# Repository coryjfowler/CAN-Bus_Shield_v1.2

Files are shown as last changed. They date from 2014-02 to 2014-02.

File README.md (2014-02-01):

CAN-Bus_Shield_v1.2
====================

I updated the schematic to migrate the SPI connections over to the ICSP header to allow the Shield to be compatible with other Arduinos that do not use digital pins 11-13 for SPI.  I also provided the option to select /INT pin.

This version is capable of operating at 3.3V BUT the MCP2562 still needs +5V to operate the CAN bus.  There is a solder-jumper pad to select the voltage of operation if IOREF pin is not used.

This version has two pinouts on the DE9 for CAN.  These two pinouts are not enabled by default, there are three solder-jumpers on the bottom of the PCB.  The dots indicate the "Standard CAN Pinout" commonly used and the opposite retains compatibility with the OBDII cable which started this whole mess.

This version features a split termination that is not enabled by default.  The split termination improves CMRR.

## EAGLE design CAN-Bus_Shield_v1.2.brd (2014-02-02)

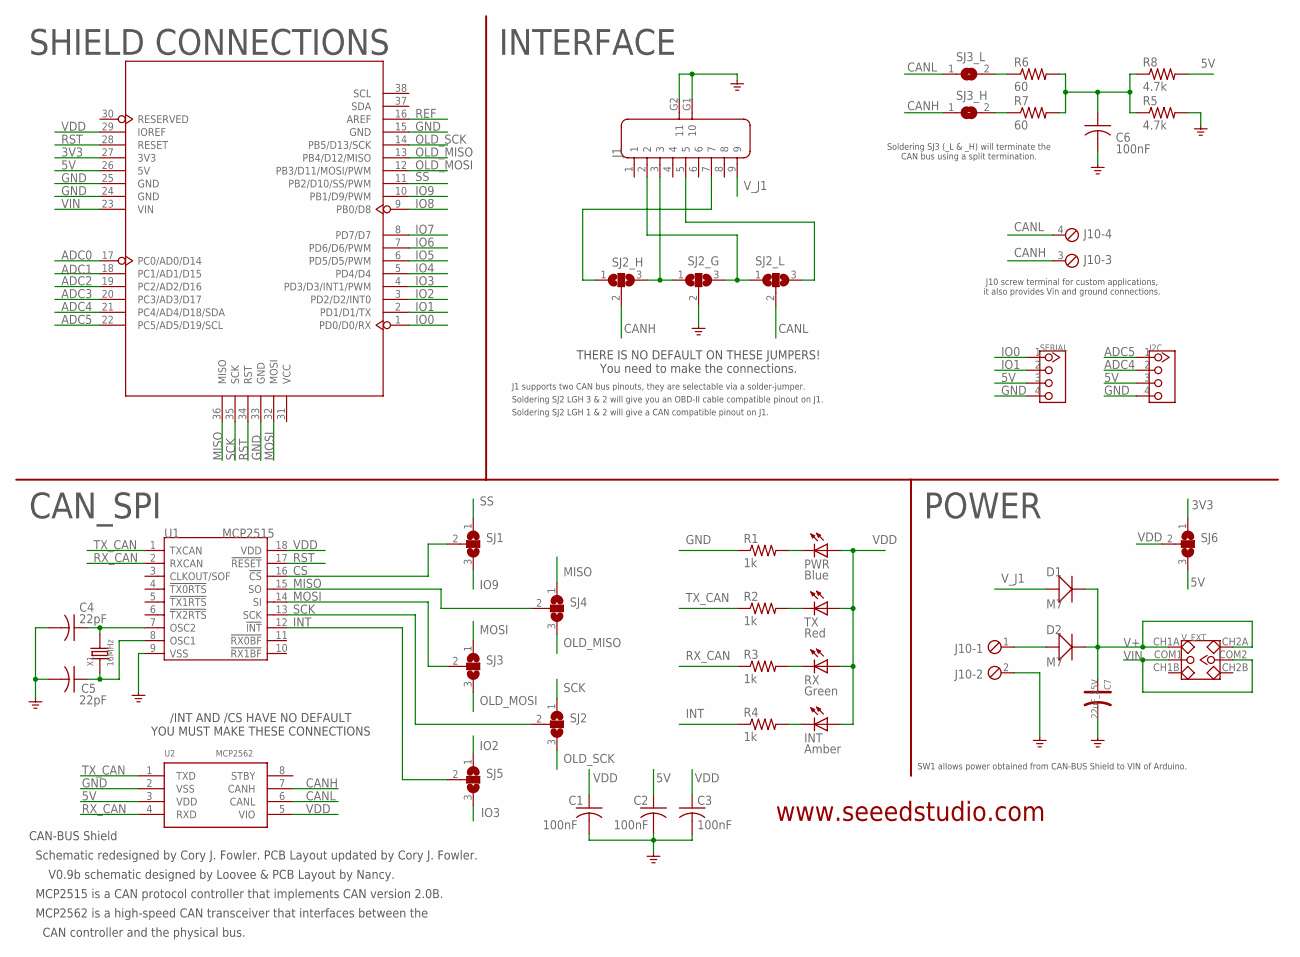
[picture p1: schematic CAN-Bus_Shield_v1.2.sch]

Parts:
C1, C2, C3: 100nF; C0603K
C4, C5: 22pF; C0603
C6: 100nF; C1210
C7: 22uF_25V; AVX-C
D1, D2: M7; D2010
I2C: TWIG-4P-2.0-2.0; 4P-2.0
INT: Amber; CHIP-LED0805
J1: DB9'MEAL'; DB9-MEAL
J10: MPT4; 4POL254
PWR: Blue; CHIP-LED0805
R1, R2, R3, R4: 1k; M0805
R5, R8: 4.7k; M3216
R6, R7: 60; M3216
RX: Green; CHIP-LED0805
SERIAL: TWIG-4P-2.0-2.0; 4P-2.0
SJ1, SJ2, SJ2_G, SJ2_H, SJ2_L, SJ3, SJ4, SJ5, SJ6: SJ2W; SJ_2
SJ3_H, SJ3_L: SJ
TX: Red; CHIP-LED0805
U1: MCP2515; SOIC18
U2: MCP2562; SO08
U3: ARDUINO
V_EXT: SWITCH-2CH-6P; 6P-2CH-2.54-7.6X3.0
X1: 16MHz; HC49/S

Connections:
3V3: SJ6.1, U3.27 (3V3)
5V: C2.1, I2C.3, R8.2, SERIAL.3, SJ6.3, U2.3 (VDD), U3.26 (5V)
ADC0: U3.17 (PC0/AD0/D14)
ADC1: U3.18 (PC1/AD1/D15)
ADC2: U3.19 (PC2/AD2/D16)
ADC3: U3.20 (PC3/AD3/D17)
ADC4: I2C.2, U3.21 (PC4/AD4/D18/SDA)
ADC5: I2C.1, U3.22 (PC5/AD5/D19/SCL)
CANH: J10.3, SJ2_H.2, SJ3_H.1, U2.7 (CANH)
CANL: J10.4, SJ2_L.2, SJ3_L.1, U2.6 (CANL)
CS: SJ1.2, U1.16 (!CS)
GND: C1.2, C2.2, C3.2, C4.2, C5.2, C6.2, C7.-, I2C.4, J1.G1 (10), J1.G2 (11), J10.2, R1.1, R5.2, SERIAL.4, SJ2_G.2, U1.9 (VSS), U2.2 (VSS), U3.15 (GND), U3.24 (GND), U3.25 (GND), U3.33 (GND)
INT: R4.1, SJ5.2, U1.12 (!INT)
IO0: SERIAL.1, U3.1 (PD0/D0/RX)
IO1: SERIAL.2, U3.2 (PD1/D1/TX)
IO2: SJ5.1, U3.3 (PD2/D2/INT0)
IO3: SJ5.3, U3.4 (PD3/D3/INT1/PWM)
IO4: U3.5 (PD4/D4)
IO5: U3.6 (PD5/D5/PWM)
IO6: U3.7 (PD6/D6/PWM)
IO7: U3.8 (PD7/D7)
IO8: U3.9 (PB0/D8)
IO9: SJ1.3, U3.10 (PB1/D9/PWM)
MISO: SJ4.1, SJ4.2, U1.15 (SO), U3.36 (MISO)
MOSI: SJ3.1, SJ3.2, U1.14 (SI), U3.32 (MOSI)
unnamed: PWR.C, R1.2
unnamed: R2.2, TX.C
unnamed: R3.2, RX.C
unnamed: J1.2, SJ2_G.3, SJ2_L.1
unnamed: J1.7, SJ2_H.1
unnamed: J1.3, SJ2_G.1, SJ2_H.3
unnamed: R6.1, SJ3_L.2
unnamed: R7.1, SJ3_H.2
unnamed: C6.1, R5.1, R6.2, R7.2, R8.1
unnamed: C5.1, U1.8 (OSC1), X1.1
unnamed: C4.1, U1.7 (OSC2), X1.2
unnamed: INT.C, R4.2
unnamed: J1.5, SJ2_L.3
OLD_MISO: SJ4.3, U3.13 (PB4/D12/MISO)
OLD_MOSI: SJ3.3, U3.12 (PB3/D11/MOSI/PWM)
OLD_SCK: SJ2.3, U3.14 (PB5/D13/SCK)
REF: U3.16 (AREF)
RST: U1.17 (!RESET), U3.28 (RESET), U3.34 (RST)
RX_CAN: R3.1, U1.2 (RXCAN), U2.4 (RXD)
SCK: SJ2.1, SJ2.2, U1.13 (SCK), U3.35 (SCK)
SS: SJ1.1, U3.11 (PB2/D10/SS/PWM)
TX_CAN: R2.1, U1.1 (TXCAN), U2.1 (TXD)
V+: C7.+, D1.-, D2.-, V_EXT.CH1A, V_EXT.CH2A
VDD: C1.1, C3.1, INT.A, PWR.A, RX.A, SJ6.2, TX.A, U1.18 (VDD), U2.5 (VIO), U3.29 (IOREF)
VIN: U3.23 (VIN), V_EXT.COM1, V_EXT.COM2
V_J1: D1.+, J1.9
V_J10: D2.+, J10.1

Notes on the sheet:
CAN_SPI
SHIELD CONNECTIONS
INTERFACE
POWER
CAN-BUS Shield
V0.9b schematic designed by Loovee & PCB Layout by Nancy.
Schematic redesigned by Cory J. Fowler. PCB Layout updated by Cory J. Fowler.
MCP2562 is a high-speed CAN transceiver that interfaces between the
CAN controller and the physical bus.
MCP2515 is a CAN protocol controller that implements CAN version 2.0B.
www.seeedstudio.com
SW1 allows power obtained from CAN-BUS Shield to VIN of Arduino.
J1 supports two CAN bus pinouts, they are selectable via a solder-jumper.
J10 screw terminal for custom applications, it also provides Vin and ground connections.
Soldering SJ2 LGH 3 & 2 will give you an OBD-II cable compatible pinout on J1.
Soldering SJ2 LGH 1 & 2 will give a CAN compatible pinout on J1.
Soldering SJ3 (_L & _H) will terminate the CAN bus using a split termination.
THERE IS NO DEFAULT ON THESE JUMPERS! You need to make the connections.
/INT AND /CS HAVE NO DEFAULT YOU MUST MAKE THESE CONNECTIONS

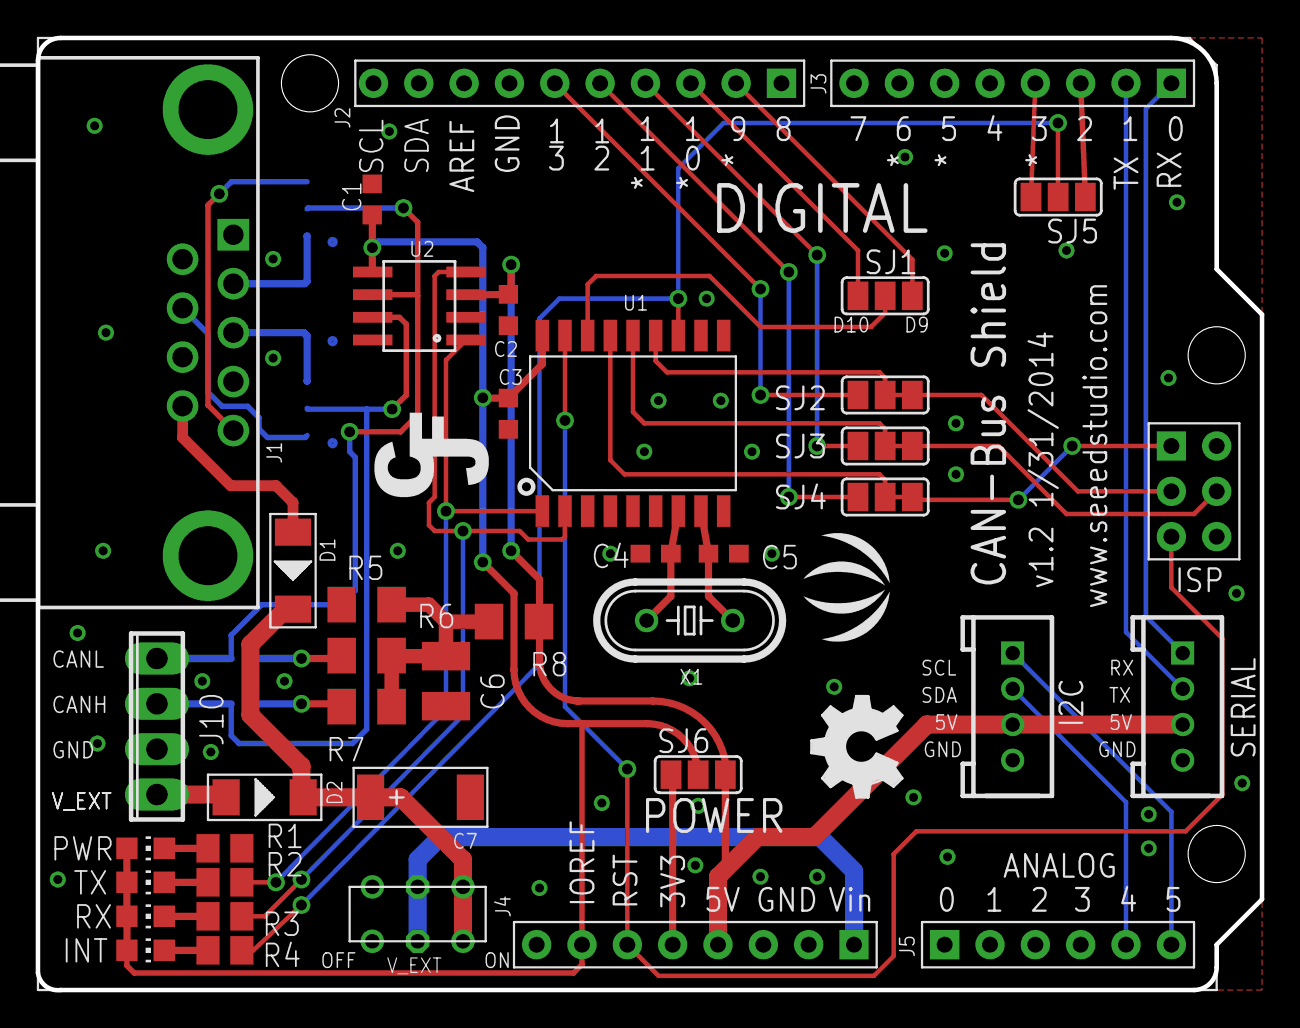
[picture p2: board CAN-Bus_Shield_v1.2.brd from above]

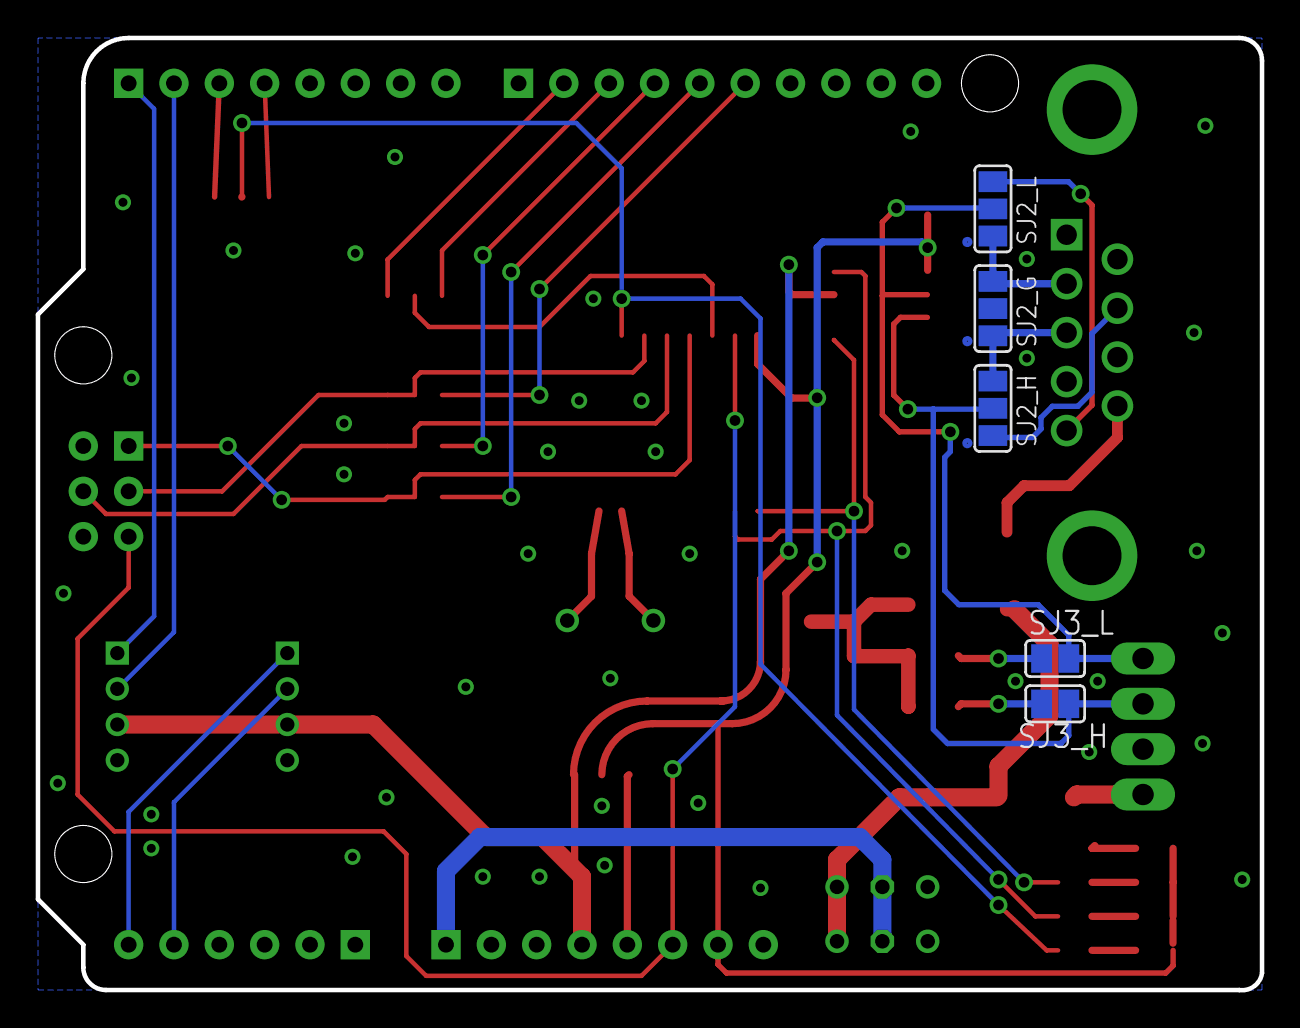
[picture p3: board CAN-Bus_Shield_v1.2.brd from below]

Board: 2 copper layers, 68.6 x 53.4 mm, 44 parts (5 on the bottom side), 42 nets.

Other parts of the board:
U$1: LOGO_SILK
U$2: OSHW_FILLX200_NOTEXT
U$9: CJF
